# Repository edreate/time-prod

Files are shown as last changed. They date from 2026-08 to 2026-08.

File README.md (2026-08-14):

# FocusDock — Focus & Availability Device

A small desk gadget that protects your focus time. It sits on your desk as a
phone dock, or clips onto the top or bottom edge of your monitor. One glance
tells you (and everyone walking by) what's going on:

- **Menu** — pick a program: Focus Timer or Available/Busy. Long-press the
  center click, from anywhere, to jump back to the menu.
- **Focus timer** — set an H:M:S duration, click to start. The screen counts
  down and the LEDs empty out like a progress bar.
- **Status light** — LEDs glow **green** (free), **red** (busy), or **amber**
  (timer running). One click toggles available/busy: an instant meeting
  indicator.
- **Phone dock** — park your phone on it and out of your hands. (Auto-detect
  of a docked phone is on the [roadmap](#roadmap).)
- **Mounts either way up** — clip it to the top or bottom monitor edge; the
  screen flips itself the right way up automatically.

## The prototype today

Everything below is running on a breadboard right now:

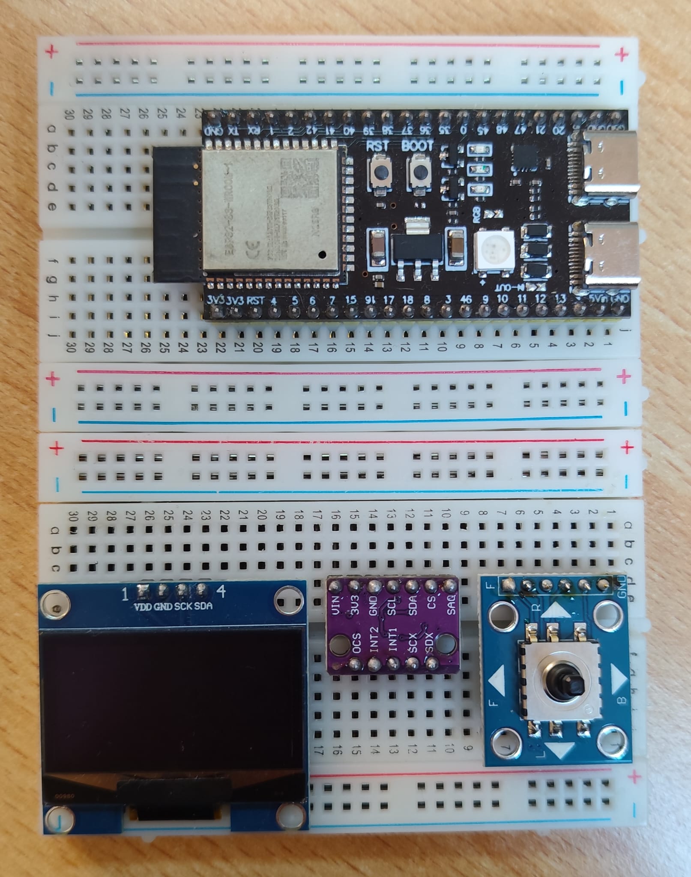
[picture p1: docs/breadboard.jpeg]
Breadboard prototype


**Working:** display, motion sensor, auto-flip, LED strip, the menu, focus
timer, pomodoro, and the available/busy status light.
**Not built yet:** Wi-Fi settings, phone-presence sensing, enclosure,
proper 5V LED power — see the [roadmap](#roadmap).

## How to use it

The 5-way button does everything:

| Button | Menu | Setting the timer | Timer running/paused | Availability |
|---|---|---|---|---|
| **Up / Down** | Move cursor | Change selected field | Down = cancel (paused) | — |
| **Left / Right** | — | Select H / M / S field | — | — |
| **Click** (center) | Open program | Start | Pause / resume | Toggle available/busy |
| **Hold click** | — | Return to menu, from any screen | | |

When a focus session hits zero the LEDs blink green and the screen shows
*Done!* — press any button to dismiss.

## What's inside

| Part | Job | ~Price |
|---|---|---|
| ESP32-S3 board (WROOM-1 N16R8) | The brain — runs everything, provides Wi-Fi | €14.49 |
| 1.3" OLED display (128×64, I2C) | Timer and menus | €7.19 |
| BMI160 motion sensor | Detects which way up it's mounted | ~€5 |
| WS2812B LED strip | The status light | €3.89 |
| 5-way button (5DirKey) | All input | ~€1 |

Full wiring instructions, circuit diagram, and part gotchas:
**[docs/HARDWARE.md](docs/HARDWARE.md)**.
New to electronics? Every concept this project uses, explained briefly:
**[docs/ELECTRONICS.md](docs/ELECTRONICS.md)**.

## Build & flash the firmware

You need [Python 3](https://www.python.org/downloads/) and a USB-C cable.
Everything else installs itself.

1. **Plug in the board** and find its port:
   ```
   make ports
   ```
   Yours is one of the `usbmodem*` entries (not `Bluetooth-Incoming-Port` or
   `debug-console`). The board has two USB-C ports — if one doesn't respond,
   try the other. macOS can rename the port across reconnects, so re-check if
   an upload suddenly can't find it.

2. **Flash:**
   ```
   make flash PORT=/dev/cu.usbmodemXXXX
   ```
   The first run installs PlatformIO and downloads the toolchain (~2 min,
   one-time). It then uploads the firmware and opens the serial monitor so you
   can watch the device's log output. `Ctrl+C` exits the monitor.

Other targets: `make build`, `make upload`, `make monitor`, `make clean`.

**If upload hangs at "Connecting..."**: hold **BOOT**, tap **RESET**, release
**BOOT**, retry. If it fails partway with a checksum error, that's a flaky USB
connection — reseat the cable and retry.

### Test firmwares

Besides the main firmware there's a small test build for checking the
hardware — useful after wiring changes:

| `ENV` | What it checks |
|---|---|
| `time-prod-app` *(default)* | The real firmware — everything |
| `test-peripherals` | I2C scan + display + IMU readout: is everything wired and answering? |

Flash it with `make flash ENV=test-peripherals PORT=...`.

## Tweaking the firmware

Every tunable number lives in [`src/config.h`](src/config.h): pin assignments,
colors, timer defaults, thresholds. Change a value, `make flash`, done.

The code is split two ways: one header per **peripheral** in `src/hardware/`,
one header per **program** in `src/software/`. `main.cpp` is just the shell —
it owns no hardware and no program state, it routes button events to whichever
program is open and asks it to render.

Adding a sensor is one header in `src/hardware/`; adding a program is one
header in `src/software/` plus a menu row. No build config to touch either way.

Project layout:

```
src/config.h              every tunable (pins, colors, thresholds)
src/hardware/display.h    OLED panel
src/hardware/leds.h       WS2812B status light
src/hardware/imu.h        accelerometer -> screen orientation
src/hardware/buttons.h    5-way switch, debounced
src/software/timer.h      focus timer program
src/software/pomodoro.h   pomodoro program
src/software/availability.h  available / busy program
src/main.cpp              the shell: menu, dispatch, loop
src/test_peripherals.cpp  peripheral check test build
platformio.ini      build configuration (one env per firmware)
Makefile            build/upload/monitor shortcuts
docs/HARDWARE.md    parts, wiring, circuit diagram
docs/ELECTRONICS.md electronics concepts, briefly explained
```

## Roadmap

What it takes to go from breadboard to a product with a long life:

**Hardware**
- [ ] Move LED strip to proper 5V power + 74AHCT125 level shifter + 1000 µF cap
- [ ] Presence sensor for the phone dock (IR / light / pressure — pick one)
- [ ] USB-C power breakout with Schottky diode (safe dual-power)
- [ ] Scale to the full 20-30 LED ring on a 5V/3A supply
- [ ] Enclosure + monitor clip design (3D-printed first)
- [ ] Evaluate rotary encoder vs. 5-way button for the final feel
- [ ] Custom PCB once the design settles

**Firmware**
- [ ] Dock/undock actions (auto-start focus session when phone is docked)
- [x] Pomodoro program (work / short break / long break, auto-cycling)
- [ ] Settings page over the device's own Wi-Fi hotspot, saved across power-off
      (would also bring back the Info screen: SSID / IP / MAC)
- [ ] Wi-Fi client mode + NTP so the menu screen can show a clock
- [ ] Calendar integration (busy light follows your meetings automatically)
- [ ] Optional buzzer/chime when the session ends
- [ ] Over-the-air firmware updates (no cable needed)
- [ ] MQTT / Home Assistant integration
- [ ] Factory-reset gesture (e.g. hold click 10 s)

**Product**
- [ ] Session stats (focus minutes per day/week)
- [ ] Battery option + deep sleep for cable-free desks
- [ ] User-test with non-technical people; simplify anything they stumble on

## License

See [LICENSE](LICENSE).

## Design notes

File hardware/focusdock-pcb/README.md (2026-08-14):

# FocusDock Carrier Board

A two-layer carrier PCB that replaces the breadboard wiring in
[`docs/HARDWARE.md`](../../docs/HARDWARE.md). It carries **no bare ICs** — the
ESP32-S3 devkit, OLED, IMU, LED strip and 5-way button all stay as modules and
plug into headers. The board is just the wiring, plus the one passive the
electronics doc asks for (the LED series resistor) and rail decoupling.

Open `focusdock-carrier.kicad_pro` in KiCad 8 or newer (built with 10.0.5).

| | |
|---|---|
| Size | 70 × 50 mm, 3 mm corner radius |
| Layers | 2 (F.Cu / B.Cu), GND pour on both, 59 stitching vias |
| Mounting | 4 × Ø2.7 mm (M2.5), corners |
| Trace widths | 0.25 mm signal, 0.5 mm power |
| ERC | 0 errors, 0 warnings |
| DRC | 0 errors, 0 unconnected pads |

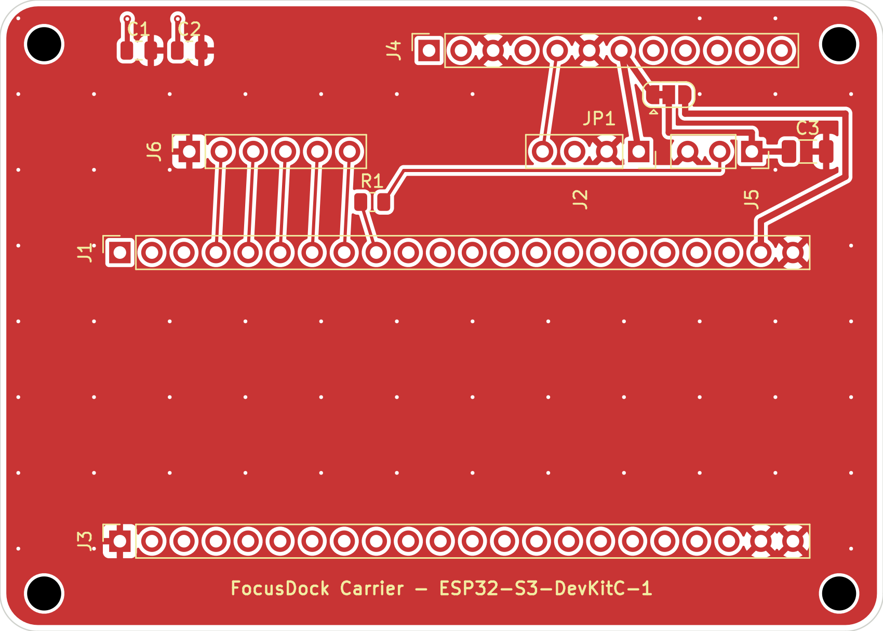
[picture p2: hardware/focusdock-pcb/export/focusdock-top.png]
Top


## How the devkit mounts

The ESP32-S3-DevKitC-1 has no bundled KiCad footprint, so it is modelled as
**two 1×22 female sockets** (J1 / J3) that the devkit plugs into like a shield.
The spacing is not a guess — it was measured from Espressif's own mechanical
DXF (`DXF_ESP32-S3-DevKitC-1_V1.1_20220429.dxf`):

| Measurement | Value |
|---|---|
| Header row pitch (J1 ↔ J3) | **22.86 mm** (0.900 in) |
| Pin pitch | 2.54 mm |
| Pins per row | 22 |
| Devkit outline | 62.74 × 25.40 mm |
| Devkit drill | Ø1.02 mm |

Pin 1 of both rows is at the **antenna** end; the USB ports are at the pin-22
end. The devkit body spans roughly x 21.5–84.3, y 38.7–64.1 on this board, so
every peripheral connector sits *above* it and stays reachable once the devkit
is seated.

## Connectors

Pin 1 is the square pad on every header. Full legend is also printed on the
back silkscreen.

| Ref | Part | Pins (1 → n) |
|---|---|---|
| **J1** | Devkit socket, row J1 | `3V3 3V3 RST 4 5 6 7 15 16 17 18 8 3 46 9 10 11 12 13 14 5V G` |
| **J3** | Devkit socket, row J3 | `G TX RX 1 2 42 41 40 39 38 37 36 35 0 45 48 47 21 20 19 G G` |
| **J2** | OLED, 1×4 | `VDD GND SCK SDA` |
| **J4** | BMI160 IMU, 1×12 | `VIN NC GND SCL SDA SA0 CS NC NC NC NC NC` |
| **J5** | WS2812B strip, 1×3 | `VDD DIN GND` |
| **J6** | 5DirKey V1-2, 1×6 | `GND F B L R CLICK` |

`J6` pins are named by the button module's **physical silkscreen** (F/B/L/R),
not the logical directions the firmware uses — `buttonsPoll()` in
`src/hardware/buttons.h` does that remap. See the button-mapping section of
[`CLAUDE.md`](../../CLAUDE.md).

## Net map

Matches the wiring table in `docs/HARDWARE.md` pin for pin.

| Net | Devkit pin | Goes to |
|---|---|---|
| `+3V3` | J1/1, J1/2 | J2/1, J4/1 (VIN), J4/7 (CS, tied high for I2C mode), JP1/1, C1, C2 |
| `GND` | J1/22, J3/1, J3/21, J3/22 | pour → every module ground, J4/6 (SA0 → 0x68) |
| `I2C_SDA` | J1/12 (GPIO8) | J2/4, J4/5 |
| `I2C_SCL` | J1/15 (GPIO9) | J2/3, J4/4 |
| `LED_DATA` | J1/9 (GPIO16) | R1 (330 Ω) |
| `LED_DIN` | — | R1 → J5/2 |
| `LED_VDD` | — | JP1/2 → J5/1, C3 |
| `+5V` | J1/21 | JP1/3 |
| `BTN_F` | J1/4 (GPIO4) | J6/2 |
| `BTN_B` | J1/5 (GPIO5) | J6/3 |
| `BTN_L` | J1/6 (GPIO6) | J6/4 |
| `BTN_R` | J1/7 (GPIO7) | J6/5 |
| `BTN_CLICK` | J1/8 (GPIO15) | J6/6 |

`J4/2` (the BMI160 breakout's `3V3` pin) is deliberately left unconnected — it
is the module regulator's *output*, and driving it is the mistake
`docs/HARDWARE.md` warns about. All other IMU aux pins (INT1/INT2/OCS/SCX/SDX)
are unconnected too, as are the 19 devkit GPIOs the firmware doesn't use.

## JP1 — LED supply selector

`docs/HARDWARE.md` runs the WS2812B at 3.3 V for bring-up but notes 5 V is the
real spec. JP1 makes that a solder-jumper choice instead of a board respin:

```
  +3V3  1 ──┐
            ├── 2  LED_VDD  →  J5/1, C3
   +5V  3 ──┘
```

Ships with **1–2 bridged (3.3 V)**, matching the current firmware and docs. To
move to 5 V, cut the 1–2 bridge and solder 2–3 — and read the power note in
`docs/HARDWARE.md` first: at 5 V the 3.3 V data line is marginal and wants the
74AHCT125 level shifter that is still on the roadmap.

## Files

```
focusdock-carrier.kicad_pro/.kicad_sch/.kicad_pcb   the project
export/                                            SVG + PNG previews
fab/gerbers/                                       gerbers + Excellon drill
fab/focusdock-carrier-bom.csv                      BOM
fab/focusdock-carrier-pos.csv                      pick-and-place
```

`fab/` is generated output — regenerate it from the project rather than
editing it.

## Before you order

- **Verify the J4 pin order against your actual BMI160 breakout.** The board is
  wired for the common GY-BMI160 12-pin order listed above. Breakouts sold under
  the same name do vary; a mismatch makes that one connector wrong.
- The four `MountingHole_2.7mm` DRC warnings ("does not match copy in library")
  are cosmetic — the footprints were created as local variants.
- No enclosure dimensions were available, so the outline is a plain rounded
  rectangle sized to the devkit. The monitor-clip / phone-dock mechanics in the
  README roadmap are not accounted for.

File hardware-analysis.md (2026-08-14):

# FocusDock Hardware Analysis — 5 V Rail, Power Budget, Programmability

Analysis of the carrier board in [`hardware/focusdock-pcb/`](hardware/focusdock-pcb/README.md)
against the wiring in [`docs/HARDWARE.md`](docs/HARDWARE.md), answering three
questions:

1. Does the WS2812B strip need a 5 V rail rather than the 3.3 V it runs on today?
2. If so, does it need a *separate* 5 V supply, given the device is USB-powered only?
3. How does the board stay programmable once it is powered that way?

Every number below is from a primary source — Espressif's own schematic, the
WS2812B datasheet, and the diode datasheet — not from a quoted figure.

Power architecture

*Source: [`docs/power-architecture.drawio`](docs/power-architecture.drawio) —
open in [draw.io](https://app.diagrams.net) or the VS Code Draw.io extension.
Re-export to SVG after editing.*

---

## 1. Current state (verified)

The board as committed:

| Check | Result |
|---|---|
| ERC | **0 errors, 0 warnings** |
| DRC | **0 errors, 0 unconnected pads, 0 footprint errors** |
| Remaining DRC warnings | 4 × `MountingHole_2.7mm` "does not match copy in library" — cosmetic, locally created footprint variants |
| Netlist vs `docs/HARDWARE.md` | matches pin for pin |
| J1/J3 pinout | confirmed twice: measured from Espressif's mechanical DXF, and cross-checked against the official schematic |

Firmware inputs that set the power budget (`src/config.h`):

```
#define NUM_LEDS       10    // 10 LEDs = one per 10% of the timer
#define LED_BRIGHTNESS 60    // 0-255; capped low on purpose (power budget)
```

### What the board does today

`JP1` is a 3-pad solder jumper selecting the LED supply, shipped bridged 1–2 =
**3.3 V**, matching current firmware and docs. The 5 V position routes `J1/21`
(the devkit's `VCC_5V` pin) to the strip.

### Gap found

**The board has JP1's 5 V position but no level shifter.** Selecting 5 V today
produces a data line that is out of spec — see §4. This is the one real defect
this analysis turned up, and it is why the 5 V option is not yet usable as
built.

---

## 2. The devkit's power architecture

From [Espressif's ESP32-S3-DevKitC-1 schematic](https://dl.espressif.com/dl/schematics/SCH_ESP32-S3-DevKitC-1_V1.1_20221130.pdf):

```
  USB-UART port ──VBUS──┐
                        ├──[1N5819HW-7-F]──> VCC_5V ──┬──> J1 pin 21 (header)
  native USB port ─VBUS─┘   (diode-OR, one per port)  └──> SGM2212-3.3 LDO ──> VCC_3V3
```

| Component | Part | Rating |
|---|---|---|
| USB input diodes (×2) | `1N5819HW-7-F` | 40 V, **1 A** avg forward current, Vf ≈ 0.3 V at a few hundred mA |
| 3.3 V regulator | `SGM2212-3.3XKC3G/TR` | feeds the ESP32-S3 module |

Two consequences drive everything below:

- The **1 A diode rating is a hard ceiling** on the 5 V pin, and it is *shared*
  with the LDO powering the ESP32-S3.
- The diode drop means the "5 V" pin is really **~4.7 V** under load. That
  quietly lowers the WS2812B's logic threshold, which matters in §4.

---

## 3. Do we need a 5 V rail? — Yes

`docs/HARDWARE.md` describes 3.3 V operation as "colors may look dim or wrong."
The datasheet is stronger than that.

[WS2812B datasheet](https://cdn-shop.adafruit.com/datasheets/WS2812B.pdf):
supply voltage range **3.5 – 5.3 V**, with electrical characteristics tested at
4.5 – 5.5 V.

**At 3.3 V the part is below its datasheet minimum** — not degraded,
unspecified. So yes, a 5 V rail is the correct design, and JP1 exists for
exactly this reason.

### Do we need a *separate* 5 V supply? — Not yet

USB VBUS is already 5 V, so **no boost converter belongs in this design.** The
only question is whether VBUS reaches the LEDs *through* the devkit or *around*
it. That is a current-budget question:

| Load | Current |
|---|---|
| `1N5819HW` rating (hard ceiling) | 1000 mA |
| ESP32-S3 peak (Wi-Fi TX, drawn through the LDO) | ~350 mA |
| **Headroom at the 5 V pin** | **~500 mA peak, ~300 mA continuous** |
| **10 LEDs @ `LED_BRIGHTNESS 60`, all white** | **~150 mA** ✅ fits |
| Typical status colour at that brightness | ~50 mA ✅ |
| Roadmap 20–30 LED ring, full white | ~1800 mA ❌ **12× over** |

- **Today (10 LEDs):** no separate supply. 150 mA against ~300 mA of headroom.
  Route it through the devkit's 5 V pin — that is what JP1 already does.
- **Roadmap ring:** yes. 1.8 A cannot pass through a 1 A diode. VBUS must reach
  the LEDs without going through the devkit at all.

---

## 4. The real problem is logic level, not current

The WS2812B needs `VIH = 0.7 × VDD`. The ESP32-S3 drives 3.3 V:

| LED VDD | Source | VIH needed | Margin | Verdict |
|---|---|---|---|---|
| 3.3 V | JP1 → 3V3 (today) | 2.31 V | +0.99 V | data OK, but **VDD below spec** |
| 4.7 V | JP1 → 5 V, after devkit diode drop | 3.29 V | **+0.01 V** | **fails** |
| 5.0 V | direct from VBUS | 3.50 V | **−0.20 V** | **fails** |
| 4.3 V | 5 V minus one series diode | 3.01 V | +0.29 V | ✅ passes |
| any | through a 74AHCT125 buffer | — | full 5 V swing | ✅ passes |

The +0.01 V row explains why 5 V "sometimes works" on boards like this — the
Schottky drop lowers VIH just enough to scrape by. That is luck, not margin,
and it varies with load current and temperature.

**Conclusion: any move to 5 V requires fixing the data line.** Two ways to do
that, below.

---

## 5. What is needed

### Now — make the 5 V jumper position usable

Recommended: a single-gate buffer on the LED data line.

| Ref | Part | Package | Purpose |
|---|---|---|---|
| U1 | **`SN74AHCT1G125DBVR`** | SOT-23-5 | 3.3 V → 5 V buffer for `LED_DIN` |
| C4 | 100 nF | 0805 | U1 decoupling |

Why AHCT specifically: it runs from 5 V but has **TTL input thresholds
(VIH = 2.0 V)**, so a 3.3 V signal reads solidly high and the output swings a
full 5 V. The quad version `SN74AHCT125` (SOIC-14, or `-N` in DIP for
breadboarding) is the part Adafruit recommends universally for WS2812; the
single-gate variant is the better fit here because only one channel is needed.

**Cheaper one-part alternative:** put a series diode in the LED VDD line to drop
the rail to ~4.3 V, which pulls VIH down to 3.01 V. Another `1N5819HW-7-F` does
it — the same part the devkit already uses. Smaller and cheaper, at the cost of
slightly dimmer LEDs. Adequate for 10 LEDs; an `SS34` (3 A) would be needed at
ring scale.

Board changes either way: one part, one net split (`LED_DIN` becomes
`LED_DIN_3V3` → buffer → `LED_DIN_5V`), and a re-route of the LED data trace.

### Later — the 20–30 LED ring

Only worth doing once draw exceeds ~300 mA. Requires bringing VBUS onto the
carrier board directly:

| Part | Suggested | Notes |
|---|---|---|
| USB-C receptacle | **`HRO TYPE-C-31-M-12`** (JLCPCB `C165948`) or **`GCT USB4085-GF-A`** | 16-pin power-only; the ubiquitous cheap part |
| CC resistors | 2 × **5.1 kΩ 1%** | one on CC1 **and** one on CC2 — separate resistors, never shared |
| Bulk capacitor | **`Panasonic EEU-FR1A102`** (1000 µF, 10 V) | the cap `docs/HARDWARE.md` already calls for |
| Protection | 2 A polyfuse, e.g. `Littelfuse 1812L200/16MR` | or a soft-start load switch (`TI TPS22965DSGR`) to avoid inrush tripping the port |
| Level shifter | as above | still required — more so at a true 5.0 V rail |

Wiring: carrier VBUS feeds the LED rail directly (wide trace, bulk cap) **and**
back-feeds the devkit's 5 V pin to power the devkit.

---

## 6. Programmability — already solved by the devkit's diodes

Powering a devkit through its 5 V pin usually raises a back-feed concern. Here
it does not, and the reason is the same `1N5819HW` from §2.

Both diodes are oriented **VBUS → `VCC_5V`**. Injecting 5 V *into* the 5 V pin
reverse-biases them, so **no current can flow back out to either USB host**.

Therefore:

- Both devkit USB ports (UART and native) stay fully free for flashing.
- **Both cables may be plugged at once.** A carrier USB-C sits at 5.0 V; the
  devkit's path reaches `VCC_5V` at only ~4.7 V after its diode, so the external
  supply simply wins and the devkit's diode blocks. No conflict, no back-feed.
- Auto-reset (the DTR/RTS transistor pair on the devkit) is untouched — the
  `make flash PORT=...` workflow is unaffected.
- Single-cable operation through the devkit's own USB works today and needs no
  new connector at all.

---

## 7. Recommendation

1. **Add `SN74AHCT1G125DBVR` + 100 nF to the carrier board** and move JP1's
   default to 5 V. Small, contained revision; it makes the existing 5 V jumper
   position honest and brings the WS2812B inside its specified supply range.
2. **Defer the USB-C input.** It only earns its place above ~300 mA, i.e. when
   the LED ring actually lands. Adding it now buys nothing and costs a
   connector, CC resistors, a fuse, wide traces, and a bulk cap.
3. **Leave the 74AHCT125 note in `docs/HARDWARE.md` as-is** — it was right; this
   analysis just supplies the numbers behind it and picks the package.

## Open items

- `J4` (IMU) pin order is wired for the common GY-BMI160 12-pin order and
  remains unverified against the physical module. Printed on the back
  silkscreen so it can be checked against a bare board.
- No enclosure dimensions available; the outline is a plain rounded rectangle
  sized to the devkit, with no allowance for the monitor-clip / phone-dock
  mechanics on the README roadmap.
- Spare devkit GPIOs are unconnected rather than broken out to an expansion
  header — worth reconsidering when the roadmap's presence sensor lands.

## Sources

- [ESP32-S3-DevKitC-1 schematic v1.1](https://dl.espressif.com/dl/schematics/SCH_ESP32-S3-DevKitC-1_V1.1_20221130.pdf) — power tree, diodes, LDO, header nets
- [ESP32-S3-DevKitC-1 mechanical DXF](https://dl.espressif.com/dl/schematics/esp_idf/DXF_ESP32-S3-DevKitC-1_V1.1_20220429.dxf) — 22.86 mm row spacing, pin order
- [WS2812B datasheet](https://cdn-shop.adafruit.com/datasheets/WS2812B.pdf) — 3.5–5.3 V supply range, `VIH = 0.7 × VDD`
- [1N5819HW-7-F datasheet](https://www.mouser.com/ProductDetail/Diodes-Incorporated/1N5819HW-7-F?qs=NQ47qNm99eDyWTEd07miYA%3D%3D) — 40 V, 1 A, Vf

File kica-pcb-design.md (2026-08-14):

# FocusDock KiCad PCB — Setup Log & Plan

Goal: replace the breadboard wiring in `docs/HARDWARE.md` with a real KiCad
project the user can open and verify — a **carrier board** with headers/
connectors for the existing breakout modules (not a from-scratch redesign
with bare ICs).

## Decisions made

- **Approach:** carrier board with headers — keep the ESP32-S3 devkit, OLED
  breakout, BMI160 breakout, 5DirKey button, and WS2812B strip as-is; the PCB
  just replaces the jumper wires between them.
- **KiCad version:** target KiCad 8-compatible output — but see below, we
  ended up installing **KiCad 10.0.5** (current stable as of Aug 2026)
  instead, since that's what `brew install --cask kicad` provides and the MCP
  server writes files matching whatever KiCad version generated them.

## Environment setup (done)

1. Cloned the KiCad MCP server (`mixelpixx/KiCAD-MCP-Server`) — a Node/
   TypeScript MCP server that shells out to a Python backend using KiCad's
   own `pcbnew` module to actually create/edit `.kicad_pro` / `.kicad_sch` /
   `.kicad_pcb` files.
   - Moved it to a **permanent** location (NOT the session scratchpad, which
     gets wiped): `~/mcp-servers/KiCAD-MCP-Server`
   - `npm install` (runs the TypeScript build via its `prepare` script) →
     `dist/index.js` exists.
2. Installed KiCad itself via `brew install --cask kicad` (user ran this
   manually in an interactive terminal because the cask needs `sudo` for
   `/Library/Application Support/kicad`, which a background shell can't
   prompt for). Installed at `/Applications/KiCad/KiCad.app`, version 10.0.5.
3. Created a Python venv using KiCad's *bundled* Python (required so
   `pcbnew` — a compiled C++ extension shipped inside the KiCad app — is
   importable):
   ```bash
   cd ~/mcp-servers/KiCAD-MCP-Server
   /Applications/KiCad/KiCad.app/Contents/Frameworks/Python.framework/Versions/Current/bin/python3 \
     -m venv venv --system-site-packages
   source venv/bin/activate
   pip install -r requirements.txt
   ```
   Verified: `venv/bin/python3 -c "import pcbnew, skip, PIL, cairosvg, pydantic"` → OK
   (note: the `kicad-skip` PyPI package imports as `skip`, not `kicad_skip`).
4. Registered the MCP server with Claude Code (**local** scope — this
   project only, not committed):
   ```bash
   claude mcp add kicad -s local \
     -e NODE_ENV=production \
     -e PYTHONPATH="/Applications/KiCad/KiCad.app/Contents/Frameworks/Python.framework/Versions/Current/lib/python3.9/site-packages" \
     -e LOG_LEVEL=info \
     -e KICAD_AUTO_LAUNCH=false \
     -- node "/Users/ibadrather/mcp-servers/KiCAD-MCP-Server/dist/index.js"
   ```
   This lives in `~/.claude.json` under the project entry — not part of the
   git repo.
5. User reconnected via `/mcp` so the new server's ~146 tools loaded into
   the session (`mcp__kicad__*`).

**Status: environment is fully working.** `mcp__kicad__list_symbol_libraries`
and `mcp__kicad__search_footprints` both returned real results against
KiCad's bundled libraries, e.g.:
- `RF_Module:ESP32-S3-WROOM-1` (bare module footprint — not what we need for
  the carrier-board approach, see below)
- No bundled footprint exists for the *devkit board itself*
  (`ESP32-S3-DevKitC-1`) — only the bare WROOM-1 module. Same for symbols:
  `search_symbols("ESP32-S3-DevKitC")` → no results.

## Design approach for the ESP32-S3-DevKitC-1 devkit

Since there's no ready-made KiCad footprint for the whole devkit board, plan
is to model it as **two 1×22 female pin sockets** (2.54 mm pitch) at the
correct row-to-row spacing, so the real devkit plugs into the carrier board
like a shield. This requires the *real* mechanical spacing between the two
header rows (J1/J3) — getting this wrong means the devkit physically won't
seat.

Confirmed pinout order (from Espressif's official user guide,
`docs.espressif.com/.../esp32-s3-devkitc-1/user_guide_v1.1.html`):

- **J1** (pin 1→22): `3V3, 3V3, RST, 4, 5, 6, 7, 15, 16, 17, 18, 8, 3, 46, 9, 10, 11, 12, 13, 14, 5V, G`
- **J3** (pin 1→22): `G, TX, RX, 1, 2, 42, 41, 40, 39, 38, 37, 36, 35, 0, 45, 48, 47, 21, 20, 19, G, G`

**Resolved.** Fetched Espressif's mechanical DXF
(`DXF_ESP32-S3-DevKitC-1_V1.1_20220429.dxf`) and measured the drill geometry
directly rather than trusting a quoted figure — the header holes live on the
`TOOL_BOT` layer:

| Measurement | Value |
|---|---|
| J1 row | x = 1.270 mm |
| J3 row | x = 24.130 mm |
| **Row-to-row spacing** | **22.860 mm** (0.900 in) |
| Pin pitch | 2.540 mm (22 pins, y 7.960 → 61.300) |
| Drill | Ø1.02 mm |
| Board outline | 25.40 × 62.74 mm |

Pin 1 of both rows is at the antenna end; the USB ports are at the pin-22 end.
(Note the widely-quoted "70 × 28 mm" board size on community sites is wrong —
the drawing's own dimension annotations say 62.74 × 25.40 mm.)

## Repo placement

Created at `hardware/focusdock-pcb/`, matching the existing `docs/`
convention. See [`hardware/focusdock-pcb/README.md`](hardware/focusdock-pcb/README.md)
for the board's own documentation.
## Board as built

`hardware/focusdock-pcb/focusdock-carrier.*` — 70 × 50 mm, 2 layers, GND pour
on both sides. **ERC 0/0. DRC 0 errors, 0 unconnected pads.**

Connectors: J1/J3 devkit sockets (1×22, 22.86 mm apart), J2 OLED (1×4), J4 IMU
(1×12), J5 LED strip (1×3), J6 5DirKey (1×6). Passives: R1 330 Ω in the LED
data line, C1 100 nF + C2 10 µF on 3V3, C3 100 µF on the LED rail. JP1 is a
3-pad solder jumper selecting the LED supply between 3V3 (default, bridged)
and 5V — the PCB expression of the "3.3 V for testing, 5 V later" note in
`docs/HARDWARE.md`.

Two decisions worth recording, because they drove the layout:

- **Every peripheral connector sits above the devkit footprint**, not below it.
  The devkit body covers y 38.7–64.1, so anything between the socket rows would
  be unreachable once it is seated. Putting the connectors in the strip above
  J1 also means no signal has to cross a pad row.
- **Connector pin order was chosen to match J1's pin order left-to-right**
  (+3V3, buttons, LED, SDA, SCL, +5V). J2 and J5 are rotated 180° for exactly
  this reason. That made almost every net a short monotonic run and removed the
  crossings that otherwise force vias — the buttons ended up as five straight
  8 mm traces.

Freerouting was unavailable (no Java 21, no Docker, no jar), so routing is by
hand: signals on F.Cu, I2C and the 3V3 backbone on B.Cu, GND by pour.

Generated output lives in `hardware/focusdock-pcb/export/` (SVG + PNG previews)
and `fab/` (gerbers, Excellon drill, BOM, pick-and-place).

## Still open

- **J4 pin order is an assumption.** Wired for the common GY-BMI160 12-pin
  order (`VIN NC GND SCL SDA SA0 CS NC NC NC NC NC`). Verify against the actual
  module's silkscreen before ordering — the order is printed on the back
  silkscreen, so it can be checked against a bare board too.
- No enclosure dimensions were available, so the outline is a plain rounded
  rectangle sized to the devkit. The monitor-clip / phone-dock envelope in the
  README roadmap is not accounted for.
- Spare devkit GPIOs are left unconnected rather than broken out to an
  expansion header — worth reconsidering when the presence sensor on the
  roadmap lands.
- The 74AHCT125 level shifter and the 1000 µF bulk cap remain roadmap items;
  neither is on this board.
- Four `MountingHole_2.7mm` "does not match copy in library" DRC warnings are
  cosmetic (locally created footprint variants).

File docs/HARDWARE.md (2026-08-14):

# Hardware Guide

Everything about the physical build: what parts we use, how they connect, and
the gotchas we already hit so you don't have to. New to electronics terms like
I2C, pull-up, or level shifter? Read [ELECTRONICS.md](ELECTRONICS.md) first —
it explains each concept in a few lines.

## The prototype today

Breadboard prototype

A PCB version of this exact wiring now exists: a carrier board that keeps every
module and replaces only the jumper wires. See
[`hardware/focusdock-pcb/`](../hardware/focusdock-pcb/README.md). The wiring
table below stays the source of truth — the board is built from it.

## Parts (Bill of Materials)

| Part | Exact module | What it does |
|---|---|---|
| ESP32-S3 board | ESP32-S3 WROOM-1 N16R8 devkit | The brain: runs the firmware, provides Wi-Fi |
| Display | 1.3" OLED, 128x64, I2C (4 pins, SH1106 driver) | Shows the timer and menus |
| IMU (motion sensor) | BMI160 breakout (12-pin) | Detects which way up the device is mounted |
| LED strip | WS2812B addressable RGB (SMD-WS2812B_RGB-02-ML) | The red/amber/green status light |
| 5-way button | 5DirKey V1-2 | Up/down/left/right/click input |
| Resistor | 330-470 Ω | Protects the first LED's data input |

Planned but not on the breadboard yet: presence sensor (detect a docked
phone), USB-C power breakout, 74AHCT125 level shifter, 1000 µF capacitor,
Schottky diode (see [Roadmap in the README](../README.md#roadmap)).

## Circuit diagram (breadboard prototype)

```
                          ┌─────────────────────────┐
              USB-C 5V ──►│ ESP32-S3 DevKit         │
                          │                         │
      3.3V rail ◄─────────┤ 3V3            GPIO8 ├──┼──► SDA ──┬───────────┐
      GND rail  ◄─────────┤ GND            GPIO9 ├──┼──► SCL ──┼──┬────────┼──┐
                          │                         │          │  │        │  │
                          │                GPIO16├──┼─[330Ω]─┐ │  │        │  │
                          │                         │        │ │  │        │  │
                          │  GPIO4  ◄── button UP   │        │ │  │        │  │
                          │  GPIO5  ◄── button DOWN │   ┌────▼─┴──┴───┐ ┌──▼──▼─────┐
                          │  GPIO6  ◄── button LEFT │   │ OLED display│ │ IMU BMI160│
                          │  GPIO7  ◄── button RIGHT│   │ VDD ── 3.3V │ │ VIN ─ 3.3V│
                          │  GPIO15 ◄── button CLICK│   │ GND ── GND  │ │ GND ─ GND │
                          └─────────────────────────┘   └─────────────┘ │ CS  ─ 3.3V│
                                     ▲                                  │ SA0 ─ GND │
                                     │ common pin                       └───────────┘
                               5-way button ── GND
                                                        ┌─────────────────────┐
                          LED strip:  DIN ◄─[330Ω]─ GPIO16   WS2812B strip    │
                                      VDD ── 3.3V rail (testing; 5V later)    │
                                      GND ── GND rail   └─────────────────────┘
```

Two power rails on the breadboard:

- **3.3V rail** — fed from the ESP32's `3V3` pin. Powers the display, the IMU,
  and (for now, out of spec) the LED strip.
- **GND rail** — every single part connects here. All grounds must be tied
  together or signals have no reference and nothing works reliably.

## Wiring table

| Component | Pin | Connects to | Why |
|---|---|---|---|
| Display (OLED) | VDD | 3.3V rail | Power |
| | GND | GND rail | |
| | SCK | GPIO9 (I2C SCL) | Shared I2C clock |
| | SDA | GPIO8 (I2C SDA) | Shared I2C data |
| IMU (BMI160) | VIN | 3.3V rail | Power in |
| | 3V3 | **unconnected** | This is the onboard regulator's *output*, not an input — don't feed it |
| | GND | GND rail | |
| | SCL / SDA | GPIO9 / GPIO8 | Same I2C bus as the display |
| | CS | 3.3V rail | **Must be tied high** or the chip switches to SPI mode and stops answering I2C |
| | SA0 | GND | Sets I2C address 0x68 (3.3V would make it 0x69) |
| | OCS, INT1/2, SCX/SDX | unconnected | Aux/interrupt pins we don't use (if I2C is flaky, try tying OCS high or low — floating aux pins are a known culprit) |
| LED strip | VDD | 3.3V rail (**testing**) | Out of spec — WS2812B wants 5V; see power note |
| | GND | GND rail | |
| | DIN | GPIO16 → 330-470 Ω → DIN | Resistor protects the first LED's data input |
| 5-way button | forward (up) | GPIO4 | All button pins use the ESP32's internal pull-ups, |
| | backward (down) | GPIO5 | so pressing a direction pulls the pin to GND — |
| | left | GPIO6 | no external resistors needed |
| | right | GPIO7 | |
| | center click | GPIO15 | |
| | common | GND rail | |

Pin numbers are defined once in [`src/config.h`](../src/config.h) — if you wire
something differently, change it there.

## Power notes

- WS2812B is spec'd for **5V**. We currently run it at 3.3V for bring-up
  convenience: colors may look dim or wrong (blue/green fade first). If they
  do, that's the supply, not the code — move strip VDD to the `5Vin` pin.
- One nice side effect of 3.3V: the data line matches the ESP32's 3.3V logic,
  so no level shifter is needed *yet*. At 5V VDD the 3.3V data signal is
  marginal — add the 74AHCT125 level shifter before scaling up.
- Budget: a WS2812B draws up to **60 mA at full white**, but a status color at
  our capped brightness is more like **8-10 mA**. The ≤10-LED prototype is fine
  on USB power. The full 20-30 LED ring needs a **5V/3A supply**, the level
  shifter, and a **1000 µF capacitor** across the strip's power pins.
- Firmware caps brightness in software (`LED_BRIGHTNESS` in `src/config.h`)
  so the strip can never draw enough to brown out the board.

## Decisions locked for the prototype

- Level shifter (74AHCT125) skipped for now — 3.3V data direct, short wires.
  Add it back before scaling LED count or finalizing a board.
- I2C bus: GPIO8 (SDA) / GPIO9 (SCL), shared by display + IMU.
- IMU CS tied to 3.3V (forces I2C mode). Verify against your breakout's
  silkscreen — some BMI160 boards wire CS differently.
- Display driver assumed SH1106 (typical for 1.3" I2C OLEDs). If the screen is
  blank or garbled, swap the constructor in the code for
  `U8G2_SSD1306_128X64_NONAME_F_HW_I2C`.

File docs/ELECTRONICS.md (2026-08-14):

# Electronics Concepts, Briefly

Every electronics idea this project uses, explained in a few lines each, with
the example of where it shows up in *our* circuit. No prior knowledge assumed.

## Voltage, current, ground

**Voltage** (volts, V) is electrical pressure; **current** (amps, A) is how
much electricity actually flows. A part needs the right voltage to work and
draws however much current it needs. **Ground (GND)** is the shared zero-point
that all voltages are measured against.

*In this project:* USB gives us 5V. The ESP32 board converts that to 3.3V for
its own chip and the sensors. Every part's GND pin ties to one shared GND rail
— without that common reference, parts can't understand each other's signals.

## GPIO pins

A **GPIO** (general-purpose input/output) is a pin the firmware controls: it
can output 3.3V ("high") or 0V ("low"), or read which of the two a connected
wire is at.

*In this project:* GPIO16 outputs the LED data signal; GPIO4/5/6/7/15 read the
five button directions.

## Pull-up resistors

An input pin connected to nothing "floats" — it reads random noise. A
**pull-up** weakly ties the pin to 3.3V so it reads a steady "high" until
something actively pulls it to GND. The ESP32 has pull-ups built into every
pin that firmware can switch on (`INPUT_PULLUP`).

*In this project:* each button pin idles high via its internal pull-up.
Pressing the button connects the pin to GND, so the firmware sees it go low.
That's why "pressed" is `LOW` in the code, not `HIGH`.

## I2C (the two-wire bus)

**I2C** lets many chips share just two wires: SDA (data) and SCL (clock). Each
chip has an **address** (a number like 0x68) so the ESP32 can talk to one chip
at a time, like calling a name in a room.

*In this project:* the OLED display (address 0x3C) and the IMU (0x68) share
the same two wires, GPIO8 (SDA) and GPIO9 (SCL). The `test-peripherals` firmware
scans the bus and prints every address that answers — the first thing to check
when something doesn't respond.

## Addressable LEDs (WS2812B)

A normal LED is one color and one wire per LED. A **WS2812B** strip has a tiny
chip inside every LED: you send one data signal into the strip's DIN pin, and
each LED reads its own color from the stream and passes the rest along. Any
LED, any color, three wires total.

*In this project:* GPIO16 sends the color data. A **330-470 Ω resistor** sits
in the data line to absorb signal spikes that can damage the first LED's input.

## Power budgeting

Add up the worst-case current of everything, and make sure the supply can
deliver it. Exceeding it causes a **brownout**: voltage sags and the
microcontroller resets randomly — a maddening bug if you don't know to look
for it.

*In this project:* each WS2812B can draw 60 mA at full white; 30 LEDs would be
1.8 A — way beyond what USB through the devkit can give. That's why the
firmware caps brightness in software, and why the full LED ring needs its own
5V/3A supply.

## Level shifting

Chips only reliably read a "high" signal above ~70% of their own supply
voltage. A 3.3V signal into a chip powered at 5V is right at the edge — it
might work, or might glitch. A **level shifter** (like the 74AHCT125)
translates 3.3V signals up to 5V.

*In this project:* not needed *yet* because we run the strip at 3.3V. The
moment the strip moves to proper 5V power, the ESP32's 3.3V data signal
becomes marginal and the level shifter goes in.

## Decoupling / bulk capacitors

A **capacitor** is a tiny rechargeable reservoir of charge. Placed across a
part's power pins, it smooths out sudden demand spikes the supply can't react
to fast enough.

*In this project:* when all LEDs switch on at once, the current demand jumps
instantly. A **1000 µF capacitor** across the strip's power pins (planned)
absorbs that spike — without it, the jolt can reset the ESP32 or even kill the
first LED.

## Switch bounce and debouncing

A pressed button doesn't close cleanly — the metal contacts physically bounce
for a few milliseconds, producing dozens of fake press/release events.
**Debouncing** means ignoring changes until the signal has been stable for a
while.

*In this project:* the `Button` struct in `src/hardware/buttons.h` only accepts a state
change after it has held steady for `BTN_DEBOUNCE_MS` (30 ms). Without it, one
click could jump the timer by several steps.

## Accelerometers and orientation

An **accelerometer** measures acceleration on three axes — including gravity,
which always points down at a constant 1g. Read which axis gravity appears on
and you know which way up the device is.

*In this project:* the BMI160's X axis reads about +1g mounted normally and
-1g upside down. The firmware smooths the reading (**EMA filter**), requires
it to clearly cross ±0.5g (**hysteresis** — the dead zone in between never
triggers), and to stay there for 350 ms (**debounce**) before flipping the
display. Each of those three guards kills a different kind of false trigger:
noise, wobble near the threshold, and brief bumps.

## Regulator outputs vs. inputs

Many breakout boards include their own voltage regulator. Its *output* pin
looks like a power pin but must not be fed power — two supplies fighting each
other can damage the board.

*In this project:* the BMI160 breakout's `3V3` pin is exactly that: the
onboard regulator's output. We power the board through `VIN` and leave `3V3`
unconnected.

## Chip-select and mode pins

Some chips speak multiple protocols (I2C *and* SPI) and decide which based on
the voltage on a mode pin at power-up. A floating mode pin means random
behavior.

*In this project:* the BMI160's `CS` pin must be tied to 3.3V or the chip
silently switches to SPI mode and stops answering I2C — one of the first
gotchas we hit. Its `SA0` pin picks the I2C address: GND → 0x68, 3.3V → 0x69.

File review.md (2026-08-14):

Review complete. All 10 finder angles plus the gap sweep ran, and I verified the load-bearing library-internals claims directly against .pio/libdeps/time-prod-app/.

One incident to flag first: a finder agent modified src/config.h mid-review (LED_BRIGHTNESS 60 → 200). That was not part of the PR. I reverted it (git checkout -- src/config.h); the working tree is clean and back at 60. One candidate finding that was built on the contaminated value has been dropped as refuted.

[
{
"file": "src/hardware/imu.h",
"line": 19,
"summary": "`static DFRobot_BMI160 bmi160;` runs a constructor that calls bare `Wire.begin()` at static-init, so `setup()`'s `Wire.begin(PIN_I2C_SDA, PIN_I2C_SCL)` early-returns as a no-op and the config.h I2C pins are dead.",
"failure_scenario": "Verified in .pio/libdeps/time-prod-app/DFRobot_BMI160/DFRobot_BMI160.cpp:32 — the default constructor's first statement is `Wire.begin();`. Namespace-scope statics are constructed before setup(), so the bus is initialized with the ESP32-S3 variant defaults (SDA=8/SCL=9). main.cpp:179 then calls Wire.begin(8,9), which hits the core's `if(i2cIsInit(num)){ started = true; goto end; }` and skips initPins()/i2cInit() entirely. It works today only because PIN_I2C_SDA/PIN_I2C_SCL happen to equal the variant defaults. Change config.h:6-7 to any other GPIO — the file whose own header says 'This is the one place to re-map hardware; nothing below it hardcodes a pin' — and the firmware keeps driving GPIO8/9: blank display, dead IMU, and the only diagnostic is a log_w suppressed at CORE_DEBUG_LEVEL=0."
},
{
"file": "src/hardware/imu.h",
"line": 43,
"summary": "`imuOrientation()` runs every loop pass and DFRobot's I2C read contains ~23 ms of blocking `delay()`, so this one call — not `delay(LOOP_DELAY_MS)` — sets the loop rate, and short button taps are dropped.",
"failure_scenario": "Verified in DFRobot_BMI160.cpp: I2cGetRegs does `delay(10)` before requestFrom (line 805) and `delay(1)` after each of the 12 `Wire.read()` calls (line 810), plus `delay(1)` in getRegs (line 791) = ~23 ms per call, against ~350 us of actual bus work. Arduino-ESP32's delay() is vTaskDelay with CONFIG_FREERTOS_HZ=1000, so these are real tick-granular blocks. Real loop period becomes ~33 ms (63 ms on draw passes), i.e. ~30 Hz not the 100 Hz the design assumes. Button::update() is a sampled state machine, so a press-and-release completing inside one interval never changes `reading` and is invisible — a 40 ms tap landing on a draw pass is silently lost, and a caught press needs ~66-130 ms of hold. This is why menu navigation and the hold=menu gesture will feel unreliable on hardware even though the debounce logic is correct. Gate imuOrientation() to 10-20 Hz (still 5-7x faster than FLIP_DEBOUNCE_MS=350 requires)."
},
{
"file": "src/hardware/imu.h",
"line": 30,
"summary": "`bmi160.softReset()` is called before `bmi160.I2cInit(IMU_I2C_ADDR)`, so it transmits to an uninitialized I2C address on the bus the already-initialized OLED shares — and the `== BMI160_OK` check can never fail.",
"failure_scenario": "Verified: the constructor mallocs Obmi160 but leaves `->id` and `->interface` unassigned (DFRobot_BMI160.cpp:34-35 are commented out; they are only set inside I2cInit at lines 42-43). The no-arg softReset() (line 89) calls softReset(Obmi160) -> setRegs(BMI160_COMMAND_REG_ADDR,...) -> I2cSetRegs, which does `Wire.beginTransmission(dev->id)` (line 842) with raw malloc'd garbage, writing 0x7E then 0xB6. setup() calls displayBegin() before imuBegin(), so if the garbage id lands on 0x3C the SH1106 receives 0x7E as 'set display start line' and 0xB6 as 'set page' and renders scrolled/garbled until power cycle. Separately, I2cSetRegs discards endTransmission()'s return and ends `return BMI160_OK;` (line 859), so softReset() cannot fail — the left half of the `&&` is a vacuous check and only I2cInit()'s return actually gates imuOk. Carried over from the old main.cpp, but imu.h is a new file so every line is in scope."
},
{
"file": "src/main.cpp",
"line": 112,
"summary": "`updateLeds()` forces COLOR_OFF for PROGRAM_MENU, so the available/busy status light goes dark the instant the user long-presses home — on a device whose entire purpose is a room-visible status light.",
"failure_scenario": "Open Available/Busy, click to set BUSY (strip red), then use the screen's own documented 'hold=menu' gesture. There is no availabilityReset(), so the `availability` static stays AVAIL_BUSY, but the very next updateLeds() takes the PROGRAM_MENU arm and blanks the strip. A colleague walking past sees an unlit device indistinguishable from one that is powered off. Same at boot: currentProgram starts PROGRAM_MENU, so the strip is dark where the old build showed green. The old code did this at the right depth — statusColor() (old main.cpp:246-252) was a device-level resolver consulted every frame 'regardless of what program is active'. README.md:11-13 still advertises the light as an 'instant meeting indicator'. Deeper fix: an ambient status layer the shell renders unconditionally, with per-program *Leds() as an optional claim on the strip."
},
{
"file": "src/software/pomodoro.h",
"line": 90,
"summary": "`pomodoroReset()` clears `pomoRunState` and `pomoSessionCount` but never resets `pomoPhase`, and the new menu dispatch dropped the old entry reset, so nothing in the firmware ever returns pomoPhase to PHASE_WORK.",
"failure_scenario": "Old enterProgram() (main.cpp:389-394) set pomoRunState=POMO_IDLE, pomoPhase=PHASE_WORK, pomoSessionCount=0 on every entry; the new shell replaced that with a bare `currentProgram = MENU_PROGRAMS[menuIndex]` (main.cpp:75) and relies on pomodoroReset(), which omits pomoPhase. Reachable without even leaving the screen: run a work session to completion (pomoAdvancePhase sets pomoPhase=PHASE_SHORT_BREAK), pause during the break, press down (line 165) -> pomodoroReset() -> POMO_IDLE. pomodoroDraw() then renders the header as pomoPhaseLabel(pomoPhase)='Short Break' (line 230) directly above big='25:00' (the work duration, line 211) and hint='click=start' — while clicking actually calls pomoStart(PHASE_WORK). The screen names a phase the device is neither in nor about to enter. Same stale header after a long-press exit and re-entry."
},
{
"file": "src/main.cpp",
"line": 75,
"summary": "Entering the Timer no longer restores the default H:M:S, so a user who leaves it at 00:00:00 returns to a screen whose start button silently does nothing, permanently.",
"failure_scenario": "Old enterProgram(0) set setHours=0, setMinutes=settings.focusMinutes (25), setSeconds=0, selectedField=FIELD_MINUTE on every entry. The new code assigns currentProgram only, and timerReset() touches just timerState — setHours/setMinutes/setSeconds/selectedField are file-scope statics that persist across visits. The editor wraps mod 24/60/60, so 00:00:00 is one down-press away from any value. Dial all three to zero, long-press to the menu, re-open Timer: the screen shows 00:00:00, clicking center calls timerStart(), which hits `if (totalMs <= 0) return;` (timer.h:46) and does nothing, with no message and no LED change. The state survives every subsequent menu round-trip, so the timer is dead until the user works out they must dial a duration back up."
},
{
"file": "src/software/timer.h",
"line": 124,
"summary": "In the PAUSED arm of both timerInput and pomodoroInput, click and down are independent `if`s over the same ButtonEvents, so a single poll carrying both applies both transitions — in Pomodoro's case resuming and then wiping the whole cycle.",
"failure_scenario": "Each of the five buttons is an independent debounced Button and both report `clicked` in whichever poll they settle in, so a near-simultaneous press puts both flags in one ButtonEvents. timer.h:118-126: `if (b.click)` resumes (lastTickMs=millis(), STATE_RUNNING), then control falls straight into `if (b.down)` -> STATE_SET, discarding the countdown. pomodoro.h:159-167 is worse: click resumes, then `if (b.down)` calls pomodoroReset(), dropping POMO_IDLE *and* zeroing pomoSessionCount — pause on session 3 of 4, fumble the two buttons together, and three completed work sessions vanish with the cycle restarted from zero. Making these arms mutually exclusive (else-if, or handling click last) confines each poll to one transition; note the fix has to be applied twice because the two modules are copy-paste."
},
{
"file": "src/software/timer.h",
"line": 172,
"summary": "The Set-Timer hint is 138 px wide on a 128 px panel, so the tail is clipped and the user is never told that the center click starts the timer.",
"failure_scenario": "Confirmed by two independent agents decoding the installed u8g2 font tables: for u8g2_font_6x10_tr every glyph advances 6 px, so `\"</> field ^v +/- clk=go\"` (23 chars) measures 137-138 px. displayText(0, 48, hint) draws left-aligned at x=0, so glyph 21 ('g') starts at x=126 with 2 px visible and glyph 22 ('o') is entirely outside the buffer. The user reads '</> field ^v +/- clk=' on the one screen that has no other affordance explaining how to start. This line is new in this diff — the old build had `hint = \"</> field ^v +/-\"` (95 px), which fit. Every other string in the firmware was measured and fits; the next widest is 126 px."
},
{
"file": "src/software/timer.h",
"line": 83,
"summary": "DONE_AUTO_DISMISS_MS was deleted with no replacement, so the timer's Done state blinks the LEDs and holds the screen indefinitely until a human presses a button.",
"failure_scenario": "Old handleButtons() ran `if (timerState == STATE_DONE && (millis() - doneSinceMs) > DONE_AUTO_DISMISS_MS) timerState = STATE_SET;` — the Done screen cleared itself after 60 s. The define is gone from config.h and grep for DISMISS/60000 across src/ returns nothing; timerTick() returns immediately for any non-running state, so nothing but a button press leaves STATE_DONE. A session ends while the user is in a meeting: timerLeds() blinks all 10 LEDs green at 2 Hz forever and the OLED holds a static 'Done! / 00:00:00' frame forever — OLED burn-in, wasted power on a device that caps LED brightness for its power budget, and the device never returns to reporting availability. Note pomodoroTick() *does* self-advance out of POMO_PHASE_DONE, so the two programs now disagree on whether a terminal state times out."
},
{
"file": "src/main.cpp",
"line": 43,
"summary": "MENU_COUNT is a hand-written literal decoupled from both MENU_ITEMS and MENU_PROGRAMS, and tickProgram's `default:` suppresses the one compiler check that would catch the drift.",
"failure_scenario": "Two independent breaks. (a) Bump MENU_COUNT to 4 and add a MENU_ITEMS row but forget MENU_PROGRAMS: line 75 reads one past a 3-element array, currentProgram takes a garbage value, and all four dispatch switches then match no case — blank screen (displayBeginFrame/EndFrame with nothing between), frozen LEDs, nothing responds but a long press. (b) Add to both arrays but forget MENU_COUNT: the entry is silently unreachable, since drawMenu() emits MENU_COUNT rows and the `% MENU_COUNT` wrap never lets the cursor reach index 3. PlatformIO ships -Wall so -Wswitch covers handleInput/updateLeds/drawScreen, but tickProgram's `default: break;` (line 102) suppresses it and the long-press reset if-chain (lines 59-62) is not a switch at all — so the two omissions that produce a silent runtime bug (a program that never ticks; a program that leaks state across sessions) are exactly the two with zero compile-time coverage. Fix: derive MENU_COUNT via sizeof, static_assert MENU_PROGRAMS has the same extent, and replace `default:` with explicit arms."
},
{
"file": "src/software/pomodoro.h",
"line": 190,
"summary": "COLOR_BUSY and COLOR_POMO_WORK are both 0xFF0000, so a paused pomodoro is pixel-identical to a running work block; the timer has the same blind spot from a different cause.",
"failure_scenario": "config.h:20 defines COLOR_BUSY 0xFF0000 and config.h:27 defines COLOR_POMO_WORK 0xFF0000. In pomodoroLeds(), `case POMO_RUNNING: ledsSetAll(pomoPhaseColor(PHASE_WORK))` and `case POMO_PAUSED: ledsSetAll(COLOR_BUSY)` emit the same value, so the two states are indistinguishable for 25 of every 30 cycle-minutes — the POMO_PAUSED arm is dead in effect. A user pauses a work block to take a call and everyone walking past still reads 'do not disturb'. timer.h:142-144 has the same outcome from a different cause: STATE_PAUSED shares ledsSetProgress() with STATE_RUNNING, so a paused countdown is a frozen bar that looks like a running one (the old build showed COLOR_BUSY for a paused timer). On a device whose premise is 'one glance tells everyone walking by what's going on', pause has no visible signal in either program."
},
{
"file": "Makefile",
"line": 42,
"summary": "The `monitor` target is reverted to `-p $(PORT)`, silently undoing commit 089cfbd 'monitor port', which had split the monitor port from the upload port because they are different devices.",
"failure_scenario": "Verified: 089cfbd is a dedicated one-purpose commit that changed exactly this line from `-p $(PORT)` to `-p $(MON_PORT)` and added `MON_PORT ?= /dev/cu.usbmodem59700474361` alongside `PORT ?= /dev/cu.usbmodem1101` — two distinct devices, as the ESP32-S3 devkit exposes both a native-USB CDC port and a UART-bridge port. This diff deletes MON_PORT and restores the pre-fix line verbatim. A user running the documented `make flash PORT=/dev/cu.usbmodemXXXX` uploads successfully, then gets a monitor attached to the wrong device and sees no serial output — which breaks the project's only verification path, since CLAUDE.md states 'Verification means flashing a board and reading the serial log at 115200 baud'."
},
{
"file": "src/hardware/leds.h",
"line": 26,
"summary": "The ceil expression is 32-bit signed arithmetic that overflows once the bucket count reaches ~24, blanking the bar instead of scaling it — and the same expression is duplicated in timer.h.",
"failure_scenario": "`long` is 32 bits on xtensa-esp32s3. timerAdjustField caps the timer at 23:59:59, so totalMs peaks at 86,399,000 ms; at NUM_LEDS=10 the expression peaks at 950,388,999, safely under INT32_MAX. The threshold is N <= (2147483647 - 86398999)/86399000 = 23.8. README.md:139 explicitly plans 'Scale to the full 20-30 LED ring', so setting NUM_LEDS to 24-30 in config.h — the file documented as the one place to re-map hardware — and starting a long timer gives >2.1e9: signed overflow, `lit` comes out negative, `i < lit` is false for every pixel, and the strip stays dark for the entire session. timer.h:203 has the identical expression over PROGRESS_CHARS with the same cliff, so the fix has to be found twice. Extract one `progressCells(long remaining, long total, int cells)` and widen to long long."
},
{
"file": "README.md",
"line": 7,
"summary": "The diff rewrites the README to describe a two-program menu while shipping three, and deletes the Pomodoro column from the button table — leaving a full 243-line program with no documented controls anywhere in the repo.",
"failure_scenario": "README.md:7 as changed reads '**Menu** — pick a program: Focus Timer or Available/Busy', actively replacing accurate prior text; main.cpp:42 ships three MENU_ITEMS and src/software/pomodoro.h is a complete program added by this same diff. The README then contradicts itself at line 26 ('Working: ... focus timer, pomodoro'), line 121 (the file listing) and line 146 ('[x] Pomodoro program'). The button table (line 34) lost its Pomodoro column, so bindings that appear in no doc include POMO_PAUSED + down calling pomodoroReset() — strictly more destructive than the timer's documented 'Down = cancel (paused)' because it also zeroes pomoSessionCount. Blue (COLOR_POMO_LONG_BREAK) was dropped from the status-light list at lines 11-13 though pomodoroLeds() still drives it. platformio.ini:6 and Makefile:9 repeat the same erasure. A user sees a Pomodoro row on the device that no document explains, and pressing down while paused silently restarts their 4-session cycle."
},
{
"file": "CLAUDE.md",
"line": 88,
"summary": "The CLAUDE.md added by this diff is factually wrong about the code it ships with in two ways: the 'Adding a program' recipe omits two required edit sites, and the state-machine rule describes an invariant the code does not hold.",
"failure_scenario": "CLAUDE.md:88 states the complete recipe as 'a new src/software/*.h with the shape above, a row in MENU_ITEMS/MENU_PROGRAMS, and a case in each dispatch switch' — omitting a new value in `enum Program` (main.cpp:31-37) and a bump of the `MENU_COUNT = 3` literal (main.cpp:43). An agent following it verbatim ships a menu row that is invisible and unreachable with a clean build and no warning (see the MENU_COUNT finding). main.cpp:46-47 repeats the same incomplete list, and README.md:113 understates it further as 'one header plus a menu row' when the real count is eight sites. Separately CLAUDE.md:98 states program state is 'written from that module's Input()' — but timer.h:91 sets STATE_DONE inside timerTick() and pomodoro.h:133 calls pomoAdvancePhase() from pomodoroTick(), which is how a countdown reaches Done and how pomodoro auto-cycles at all. An agent taking that clause as the invariant and refactoring the expiry write into timerInput() would make an unattended timer run past zero forever."
}
]

Did not make the 15-item cap, in rough priority order: displayCentered's negative x wrapping to ~65530 because u8g2_uint_t is uint16_t (real mechanism, no string currently wide enough to trigger it); NUM_LEDS changing 8→10 silently inside the refactor with nothing in the repo pinning the real strip length; strip.show() running unthrottled every loop pass (each call tears down and rebuilds the RMT driver on this core — ~50 malloc/free pairs per second) while drawScreen() is throttled, plus sendBuffer() pushing 1 KB over I2C every 100 ms with no dirty check; SCREEN_WIDTH defined in display.h in violation of CLAUDE.md's "every tunable is a #define here"; test_peripherals.cpp bypassing config.h with a bare Wire.begin() and its own BMI160_ADDR, so the one surviving diagnostic build drifts from the app and covers 2 of 4 peripherals; the countdown engine duplicated wholesale between timer.h and pomodoro.h (six near-identical blocks, which is why finding 7 must be fixed twice); ledsSetAll/ledsSetProgress hand-rolling loops that strip.fill() already provides; pomoTotalMs being write-only; pomodoroDraw reading DEFAULT_POMO_WORK_MIN directly instead of through pomoPhaseMinutes(), breaking the seam for the settings page the roadmap promises; and docs/HARDWARE.md:38 labelling all four direction GPIOs contrary to config.h (pre-existing, but this diff edited that page).

Verified clean, so it needn't be re-checked: both envs compile from scratch; build_src_filter matches each .cpp exactly once; no macro or type-name collisions against the pinned libs or the ESP32 core; every snprintf buffer is adequate; no millis() rollover defect; the button pin remap is byte-identical to main; and the orientation math ported faithfully with all three anti-flicker guards intact.
Now using usage credits

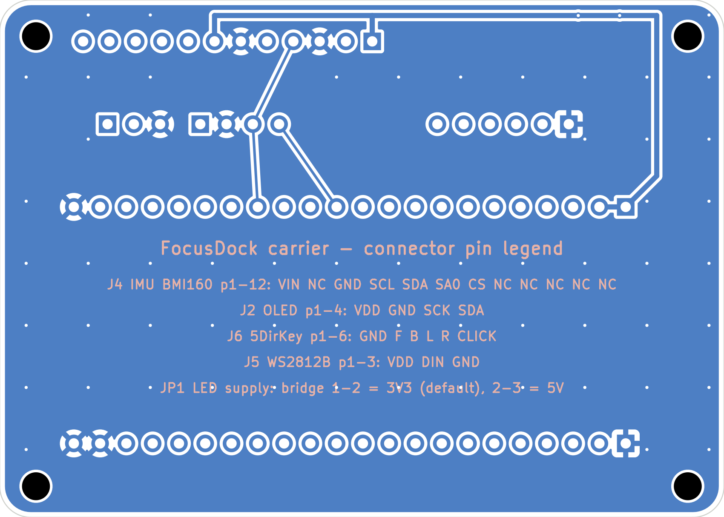
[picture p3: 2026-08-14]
hardware/focusdock-pcb/export/focusdock-bottom.png

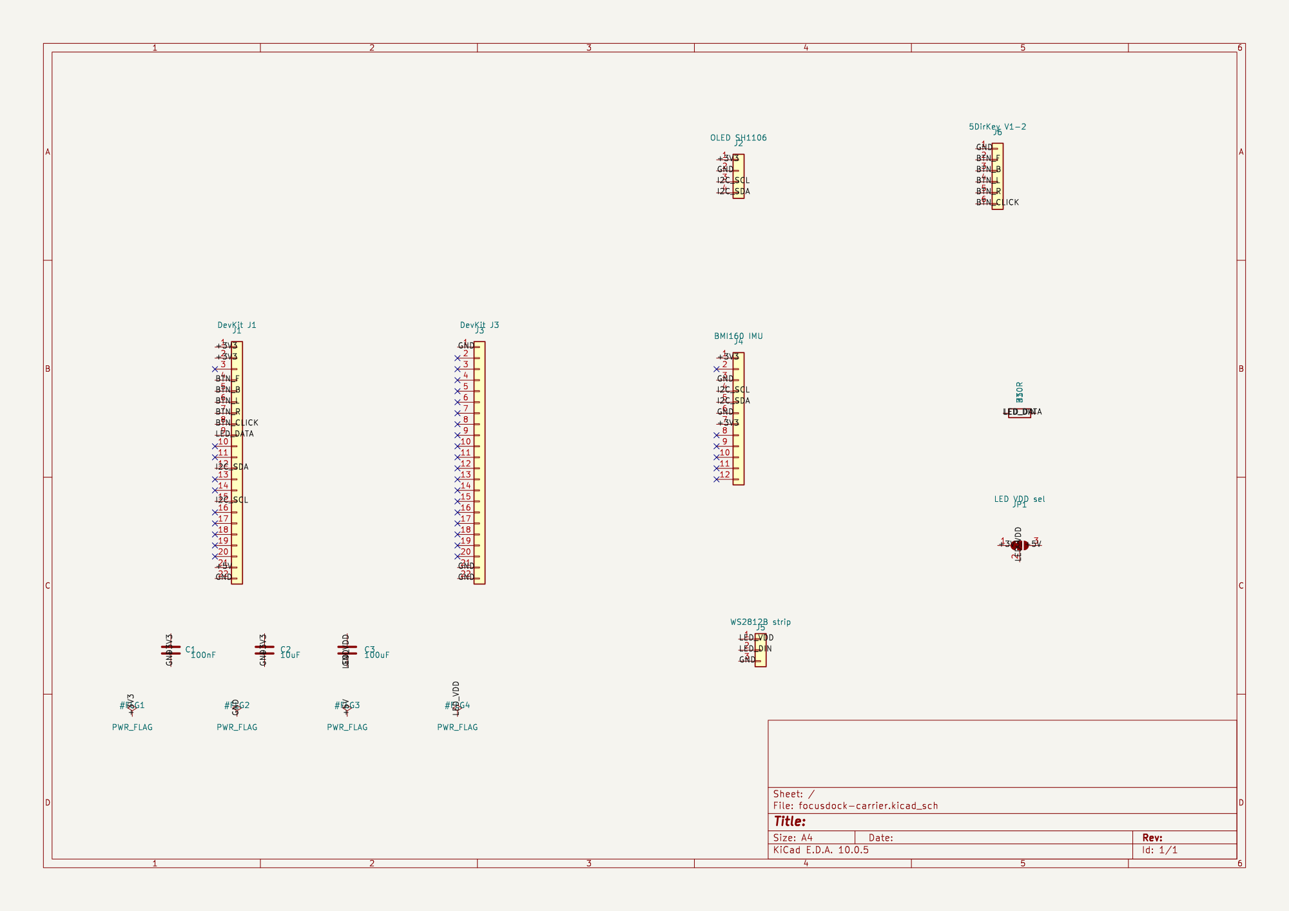
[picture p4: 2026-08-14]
hardware/focusdock-pcb/export/schematic.png

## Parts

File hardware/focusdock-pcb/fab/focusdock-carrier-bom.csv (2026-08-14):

value | footprint | quantity | references
DevKit J3 | Connector_PinSocket_2.54mm:PinSocket_1x22_P2.54mm_Vertical | 1 | ['J3']
MountingHole_2.7mm | MountingHole:MountingHole_2.7mm | 4 | ['MH1', 'MH4', 'MH2', 'MH3']
100uF | Capacitor_SMD:C_1206_3216Metric | 1 | ['C3']
LED VDD sel | Jumper:SolderJumper-3_P1.3mm_Bridged12_RoundedPad1.0x1.5mm | 1 | ['JP1']
100nF | Capacitor_SMD:C_0805_2012Metric | 1 | ['C1']
BMI160 IMU | Connector_PinSocket_2.54mm:PinSocket_1x12_P2.54mm_Vertical | 1 | ['J4']
DevKit J1 | Connector_PinSocket_2.54mm:PinSocket_1x22_P2.54mm_Vertical | 1 | ['J1']
OLED SH1106 | Connector_PinSocket_2.54mm:PinSocket_1x04_P2.54mm_Vertical | 1 | ['J2']
WS2812B strip | Connector_PinSocket_2.54mm:PinSocket_1x03_P2.54mm_Vertical | 1 | ['J5']
5DirKey V1-2 | Connector_PinSocket_2.54mm:PinSocket_1x06_P2.54mm_Vertical | 1 | ['J6']
10uF | Capacitor_SMD:C_0805_2012Metric | 1 | ['C2']
330R | Resistor_SMD:R_0805_2012Metric | 1 | ['R1']

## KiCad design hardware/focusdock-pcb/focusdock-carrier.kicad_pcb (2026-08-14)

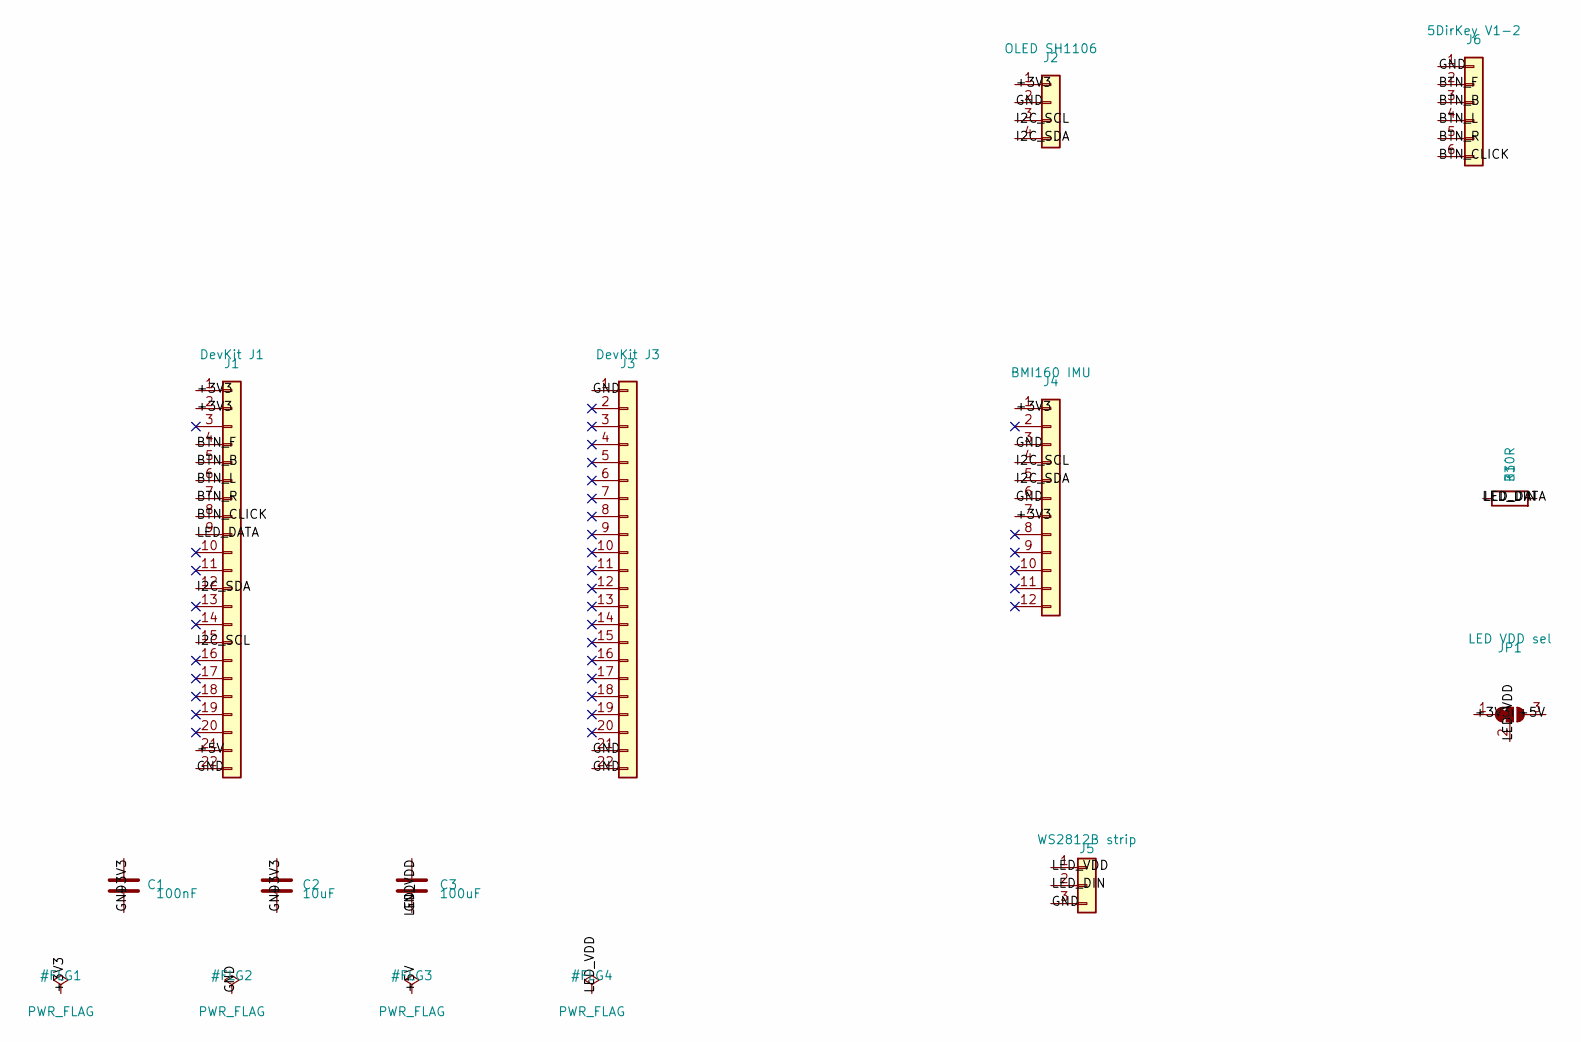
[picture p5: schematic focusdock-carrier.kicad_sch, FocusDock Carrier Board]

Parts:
C1: 100nF; C_0805_2012Metric
C2: 10uF; C_0805_2012Metric
C3: 100uF; C_1206_3216Metric
J1: DevKit J1; PinSocket_1x22_P2.54mm_Vertical
J2: OLED SH1106; PinSocket_1x04_P2.54mm_Vertical
J3: DevKit J3; PinSocket_1x22_P2.54mm_Vertical
J4: BMI160 IMU; PinSocket_1x12_P2.54mm_Vertical
J5: WS2812B strip; PinSocket_1x03_P2.54mm_Vertical
J6: 5DirKey V1-2; PinSocket_1x06_P2.54mm_Vertical
JP1: LED VDD sel; SolderJumper-3_P1.3mm_Bridged12_RoundedPad1.0x1.5mm
R1: 330R; R_0805_2012Metric

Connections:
+3V3: C1.1, C2.1, J1.1, J1.2, J2.1, J4.1, J4.7, JP1.1 (A)
+5V: J1.21, JP1.3 (B)
BTN_B: J1.5, J6.3
BTN_CLICK: J1.8, J6.6
BTN_F: J1.4, J6.2
BTN_L: J1.6, J6.4
BTN_R: J1.7, J6.5
GND: C1.2, C2.2, C3.2, J1.22, J2.2, J3.1, J3.21, J3.22, J4.3, J4.6, J5.3, J6.1
I2C_SCL: J1.15, J2.3, J4.4
I2C_SDA: J1.12, J2.4, J4.5
LED_DATA: J1.9, R1.1
LED_DIN: J5.2, R1.2
LED_VDD: C3.1, J5.1, JP1.2 (C)

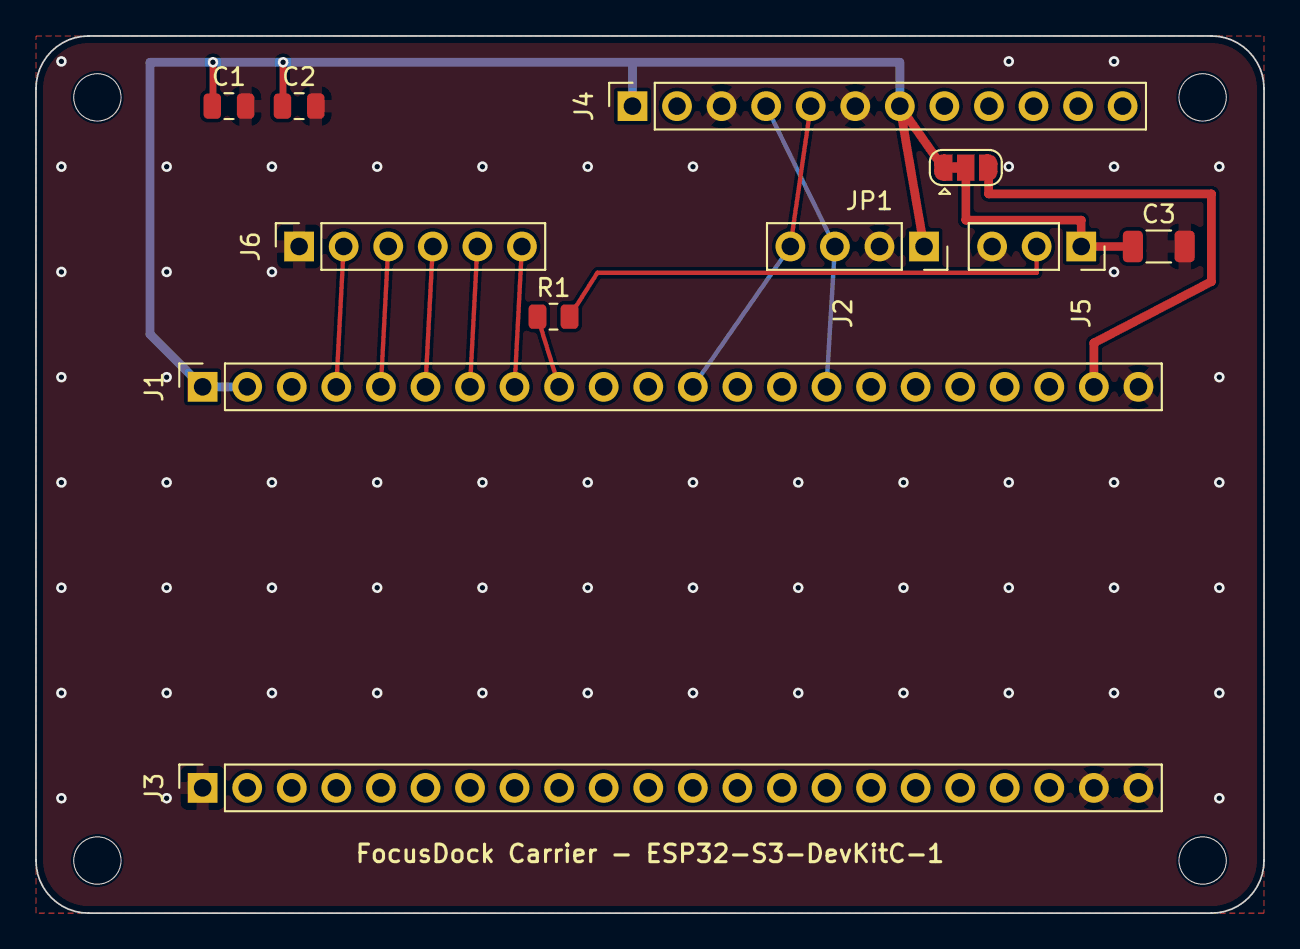
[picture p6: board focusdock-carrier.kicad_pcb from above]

Board: 2 copper layers, 70.0 x 50.0 mm, 15 parts (0 on the bottom side), 13 nets.

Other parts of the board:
MH1, MH2, MH3, MH4: MountingHole_2.7mm

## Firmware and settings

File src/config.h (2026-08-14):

// Every tunable in the firmware - pins, colors, defaults, thresholds.
// This is the one place to re-map hardware; nothing below it hardcodes a pin.
#pragma once

// ---- pins / I2C ----
#define PIN_I2C_SDA 8
#define PIN_I2C_SCL 9
#define PIN_LED_DATA 16
#define PIN_BTN_F 4 // physical "F" -> logical LEFT
#define PIN_BTN_B 5 // physical "B" -> logical RIGHT
#define PIN_BTN_L 6 // physical "L" -> logical DOWN
#define PIN_BTN_R 7 // physical "R" -> logical UP
#define PIN_BTN_PRESS 15
#define IMU_I2C_ADDR 0x68 // not BMI160_I2C_ADDR - the driver library owns that name

// ---- LEDs / colors ----
#define NUM_LEDS 10              // 10 LEDs = one per 10% of the timer
#define LED_BRIGHTNESS 60        // 0-255; capped low on purpose (power budget)
#define COLOR_AVAILABLE 0x00FF00 // green = free
#define COLOR_BUSY 0xFF0000      // red   = busy
#define COLOR_PROGRESS 0xFFA500  // amber = timer running
#define COLOR_DONE 0x00FF00      // green = timer done, blinking
#define COLOR_OFF 0x000000
#define DONE_BLINK_MS 500

// ---- pomodoro ----
#define COLOR_POMO_WORK 0xFF0000        // red   = work phase, do not disturb
#define COLOR_POMO_SHORT_BREAK 0x00FF00 // green = short break
#define COLOR_POMO_LONG_BREAK 0x0080FF  // blue  = long break
#define DEFAULT_POMO_WORK_MIN 25
#define DEFAULT_POMO_SHORT_MIN 5
#define DEFAULT_POMO_LONG_MIN 15
#define DEFAULT_POMO_SESSIONS 4         // work sessions before a long break
#define POMO_PHASE_TRANSITION_MS 3000   // blink window before auto-continuing

// ---- buttons ----
#define BTN_DEBOUNCE_MS 30
#define LONG_PRESS_MS 800 // hold this long anywhere -> back to menu

// ---- timer defaults ----
#define DEFAULT_HOURS 0
#define DEFAULT_MINUTES 25 // classic pomodoro length
#define DEFAULT_SECONDS 0

// ---- orientation ----
#define FLIP_THRESHOLD 0.5f  // g; accel-x past +/- this commits a state
#define FLIP_DEBOUNCE_MS 350 // must hold past threshold this long
#define EMA_ALPHA 0.2f       // accel smoothing, 0..1 (higher = jumpier)

// ---- loop / display ----
#define LOOP_DELAY_MS 10
#define DISPLAY_REDRAW_MS 100
#define PROGRESS_CHARS 10 // width of the on-screen timer bar, in characters

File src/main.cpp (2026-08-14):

// FocusDock - the shell: menu, program dispatch, and the main loop.
//
// Everything else lives in a module:
//   src/hardware/   one file per peripheral (display, LEDs, IMU, buttons)
//   src/software/   one file per program (timer, pomodoro, availability)
//   src/config.h    every tunable
//
// This file owns no hardware and no program state. It routes button events to
// whichever program is open, ticks it, and asks it to render.
//
// Navigation:
//   Menu          Up/Down move the cursor, click opens the program.
//   Any program   A LONG press (hold >LONG_PRESS_MS) always returns to the
//                 menu - one consistent "go home" gesture so no direction
//                 button has to be sacrificed for it.
//
// Wiring: docs/HARDWARE.md.

#include <Arduino.h>
#include <Wire.h>

#include "config.h"
#include "hardware/buttons.h"
#include "hardware/display.h"
#include "hardware/imu.h"
#include "hardware/leds.h"
#include "software/availability.h"
#include "software/pomodoro.h"
#include "software/timer.h"

enum Program
{
  PROGRAM_MENU,
  PROGRAM_TIMER,
  PROGRAM_POMODORO,
  PROGRAM_AVAILABILITY
};
Program currentProgram = PROGRAM_MENU;

// Menu rows are laid out for up to 3 entries - a 4th would collide with the
// footer hint, and would need a scrolling window like the pre-simplify build.
const char *MENU_ITEMS[] = {"Timer", "Pomodoro", "Available / Busy"};
const int MENU_COUNT = 3;
int menuIndex = 0;

// Adding a program: write src/software/<name>.h with the same
// input/tick/leds/draw shape, then add a row here and a case to each switch.
const Program MENU_PROGRAMS[] = {PROGRAM_TIMER, PROGRAM_POMODORO,
                                 PROGRAM_AVAILABILITY};

// ============================ input =================================

void handleInput(const ButtonEvents &b)
{
  // Long press is the one gesture the shell owns: leave the program, and let
  // it drop whatever it was doing.
  if (b.longClick)
  {
    if (currentProgram == PROGRAM_TIMER)
      timerReset();
    if (currentProgram == PROGRAM_POMODORO)
      pomodoroReset();
    currentProgram = PROGRAM_MENU;
    return;
  }

  switch (currentProgram)
  {
  case PROGRAM_MENU:
    if (b.up)
      menuIndex = (menuIndex - 1 + MENU_COUNT) % MENU_COUNT;
    if (b.down)
      menuIndex = (menuIndex + 1) % MENU_COUNT;
    if (b.click)
      currentProgram = MENU_PROGRAMS[menuIndex];
    break;

  case PROGRAM_TIMER:
    timerInput(b);
    break;
  case PROGRAM_POMODORO:
    pomodoroInput(b);
    break;
  case PROGRAM_AVAILABILITY:
    availabilityInput(b);
    break;
  }
}

// ======================== per-loop updates ==========================

void tickProgram()
{
  switch (currentProgram)
  {
  case PROGRAM_TIMER:
    timerTick();
    break;
  case PROGRAM_POMODORO:
    pomodoroTick();
    break;
  default:
    break; // menu and availability have nothing to advance
  }
}

void updateLeds()
{
  switch (currentProgram)
  {
  case PROGRAM_MENU:
    ledsSetAll(COLOR_OFF);
    break;
  case PROGRAM_TIMER:
    timerLeds();
    break;
  case PROGRAM_POMODORO:
    pomodoroLeds();
    break;
  case PROGRAM_AVAILABILITY:
    availabilityLeds();
    break;
  }
}

// The shell only cares that the orientation changed, not how it was measured.
void applyOrientation()
{
  static Orientation shown = ORIENT_NORMAL;
  Orientation now = imuOrientation();
  if (now != shown)
  {
    shown = now;
    displaySetFlipped(now == ORIENT_FLIPPED);
  }
}

// ============================ rendering =============================

void drawMenu()
{
  displayText(0, 10, "Select program");
  for (int i = 0; i < MENU_COUNT; i++)
  {
    char line[24];
    snprintf(line, sizeof(line), "%s%s", i == menuIndex ? "> " : "  ", MENU_ITEMS[i]);
    displayText(4, 24 + i * 13, line);
  }
  displayText(0, 62, "up/dn=move click=open");
}

void drawScreen()
{
  displayBeginFrame();
  switch (currentProgram)
  {
  case PROGRAM_MENU:
    drawMenu();
    break;
  case PROGRAM_TIMER:
    timerDraw();
    break;
  case PROGRAM_POMODORO:
    pomodoroDraw();
    break;
  case PROGRAM_AVAILABILITY:
    availabilityDraw();
    break;
  }
  displayEndFrame();
}

// ============================ setup/loop ============================

void setup()
{
  Serial.begin(115200);
  delay(500);
  Wire.begin(PIN_I2C_SDA, PIN_I2C_SCL); // shared bus: display + IMU

  displayBegin();
  ledsBegin();
  buttonsBegin();

  // A missing IMU is not fatal - the firmware just runs without auto-flip.
  Serial.println(imuBegin() ? "IMU: init OK"
                            : "IMU: init failed - auto-flip disabled this session");

  Serial.println("FocusDock ready");
}

void loop()
{
  handleInput(buttonsPoll());
  tickProgram();
  applyOrientation();
  updateLeds();

  static unsigned long lastDrawMs = 0;
  if (millis() - lastDrawMs >= DISPLAY_REDRAW_MS)
  {
    lastDrawMs = millis();
    drawScreen();
  }

  delay(LOOP_DELAY_MS);
}

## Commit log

2026-07-05 Update README with project details and specifications
    Added detailed project description, features, tech specifications, and BOM for the Focus & Availability Device.
2026-08-02 led working
2026-08-02 led timer works
2026-08-14 pcb made v0.1
    [focusdock-carrier-B_Cu.gbl, focusdock-carrier-B_Mask.gbs, focusdock-carrier-B_Silkscreen.gbo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]
